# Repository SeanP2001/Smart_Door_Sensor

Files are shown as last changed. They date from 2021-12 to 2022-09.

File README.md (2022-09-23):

# Smart Door Sensor Project

## Table of Contents

* [Table of Contents](#table-of-contents)
* [Introduction](#introduction)
* [Brief](#brief)
* [Method of Operation](#method-of-operation)
  + [Setting up The Device](#setting-up-the-device)
  + [Using the Device](#using-the-device)
* [Circuitry](#circuitry)
  + [Full Schematic](#full-schematic)
  + [Veroboard Prototype](#veroboard-prototype)
  + [PCB](#pcb)
* [Further Work](#further-work)

## Introduction

This originally started as a university project, and I have continued to develop this idea in my spare time.

## Brief

This project is a smart door alarm for security in university accommodation and hotel rooms. When somebody enters the room, the buzzer will sound, or the device will email the user. This standalone device does not require a smart hub to operate.

## Method of Operation

<p align="center">
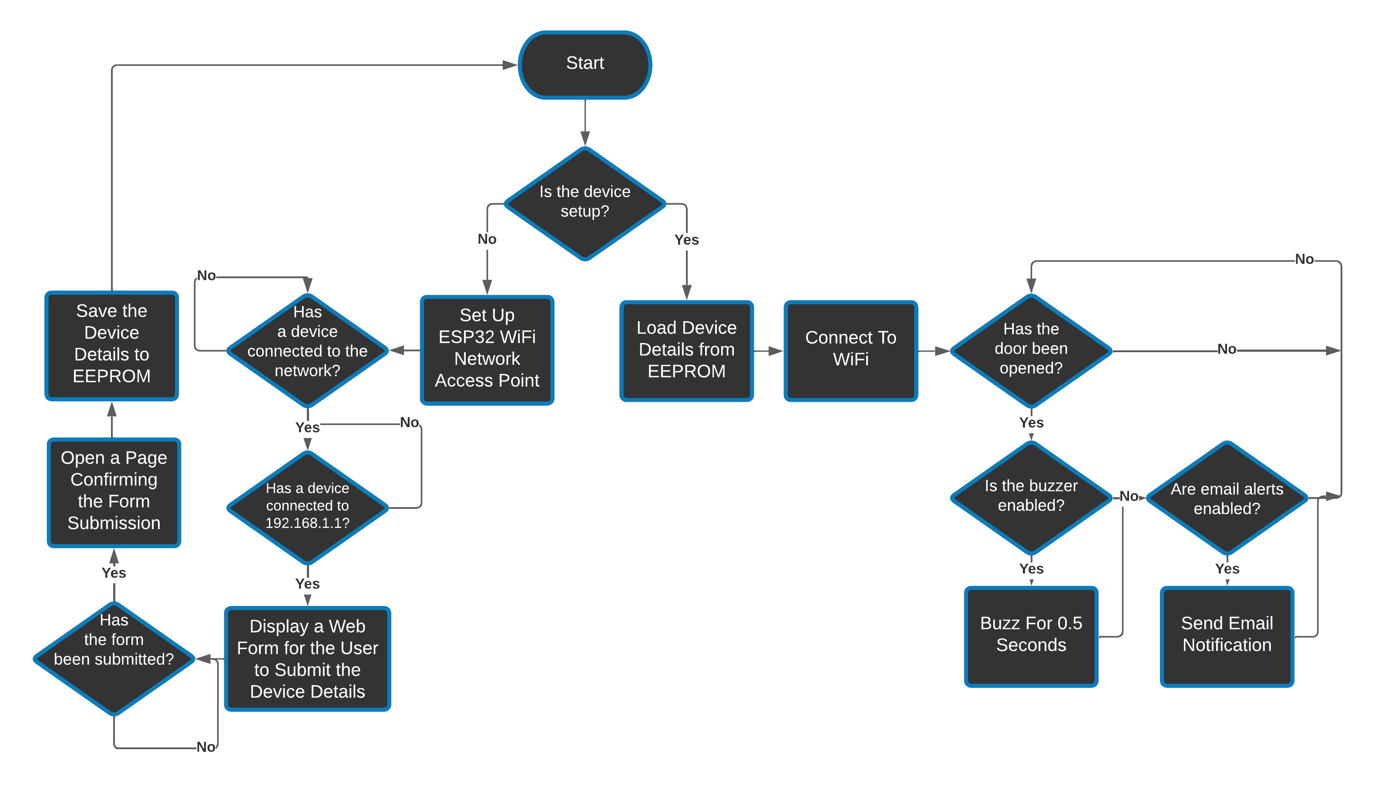
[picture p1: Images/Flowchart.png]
  
</p>

### Setting up The Device

1. Plug the device into a phone charger and switch the charger on.

2. Open the Wi-Fi settings on your smartphone and wait for the “S.P.U.D Smart
   System” network to appear. Once it appears, connect to it.

3. Turn off mobile data on your phone.

4. Open your phone’s web browser and enter “192.168.1.1” into the address bar.
   
   <p align="center">
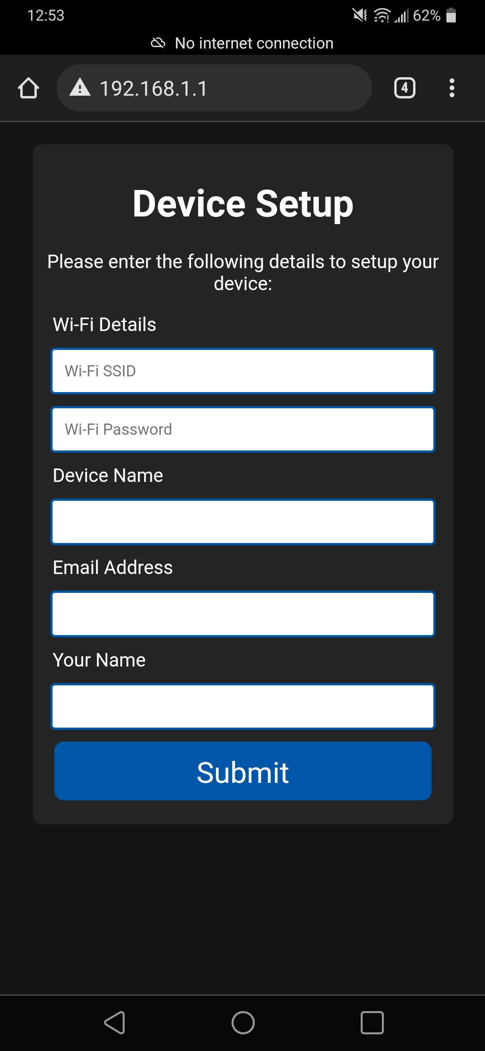
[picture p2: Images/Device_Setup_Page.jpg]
     
   </p>

5. When the page loads, input the following information:
   • Wi-Fi SSID - The name of your Wi-Fi network
   • Wi-Fi Password - Often found on the back of your Wi-Fi router
   • Device Name - The name which you want to give the device e.g., “Front Door”
   • Email Address - The email address to send notifications to
   • Your Name - The name which you want to appear on the email notifications

6. Press “Submit” and check that the credentials displayed on the next page are
   correct.

7. Wait for the LED on the device to flash green and then turn off the device and
   turn it back on again.

8. Now your device is setup.

9. Attach the sensor to the back of the door. Peel the sticky back off the main
   body and stick it to the edge of the door. Stick the magnetic contact to the
   door frame, as close to the sensor as possible. (Image showing device
   attached to door)

10. Open the door ensuring that the device does not catch on the door.

### Using the Device

<p align="center">
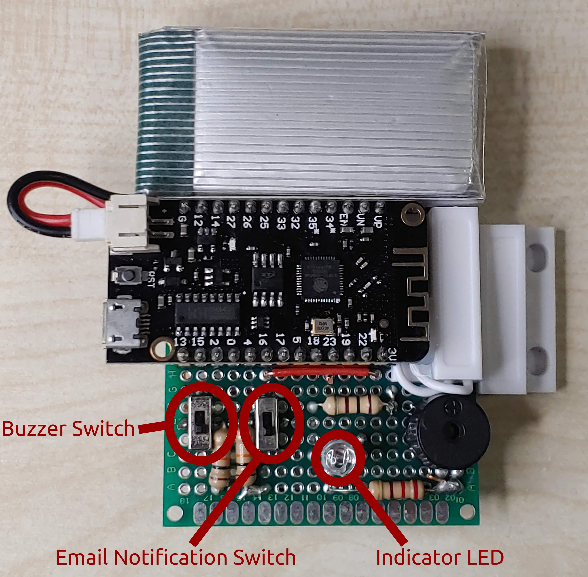
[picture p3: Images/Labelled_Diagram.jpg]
  
</p>

Switching either of the switches will alter the settings and cause the indicator LED to light (The colour of the LED shows which setting has changed).

| Indicator LED Colour | Meaning |
| --- | --- |
| Blue | Buzzer ON |
| Yellow | Buzzer OFF |
| Green | Email Notifications ON  |
| Red | Email Notifications OFF |

Depending on the settings, the sensor will either buzz or send an email notification when the door is opened.

## Circuitry

### Full Schematic

<p align="center">
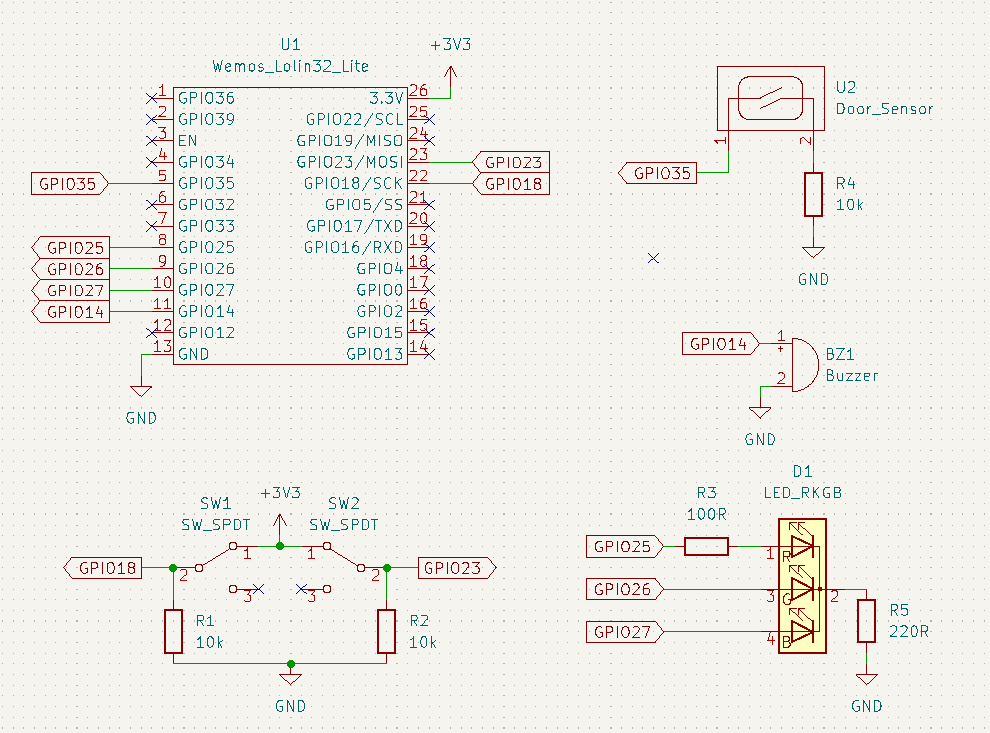
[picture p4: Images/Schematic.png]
  
</p>

### Veroboard Prototype

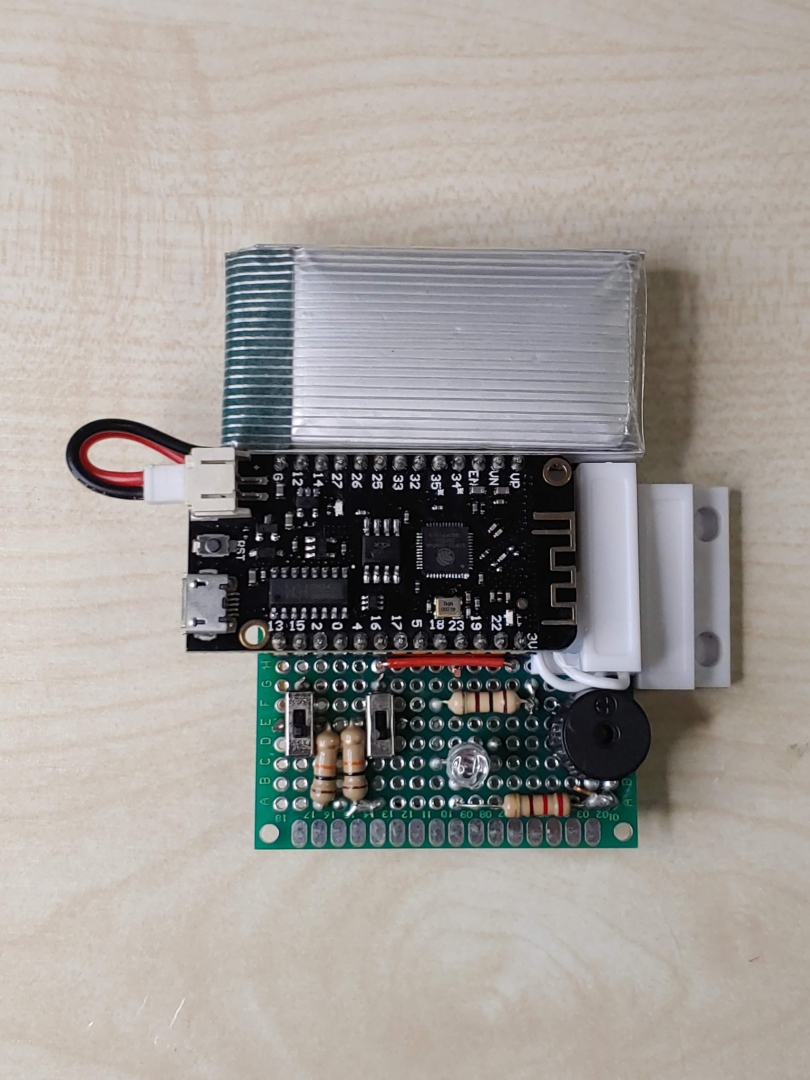
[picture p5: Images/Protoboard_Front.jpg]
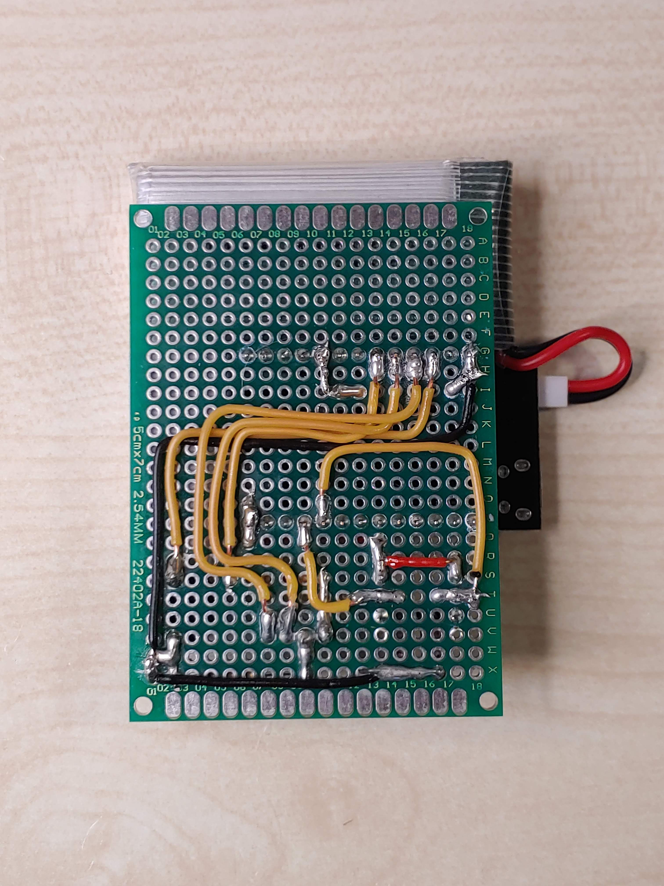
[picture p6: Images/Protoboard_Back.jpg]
|  |  |
| --- | --- |

### PCB

<p align="center">
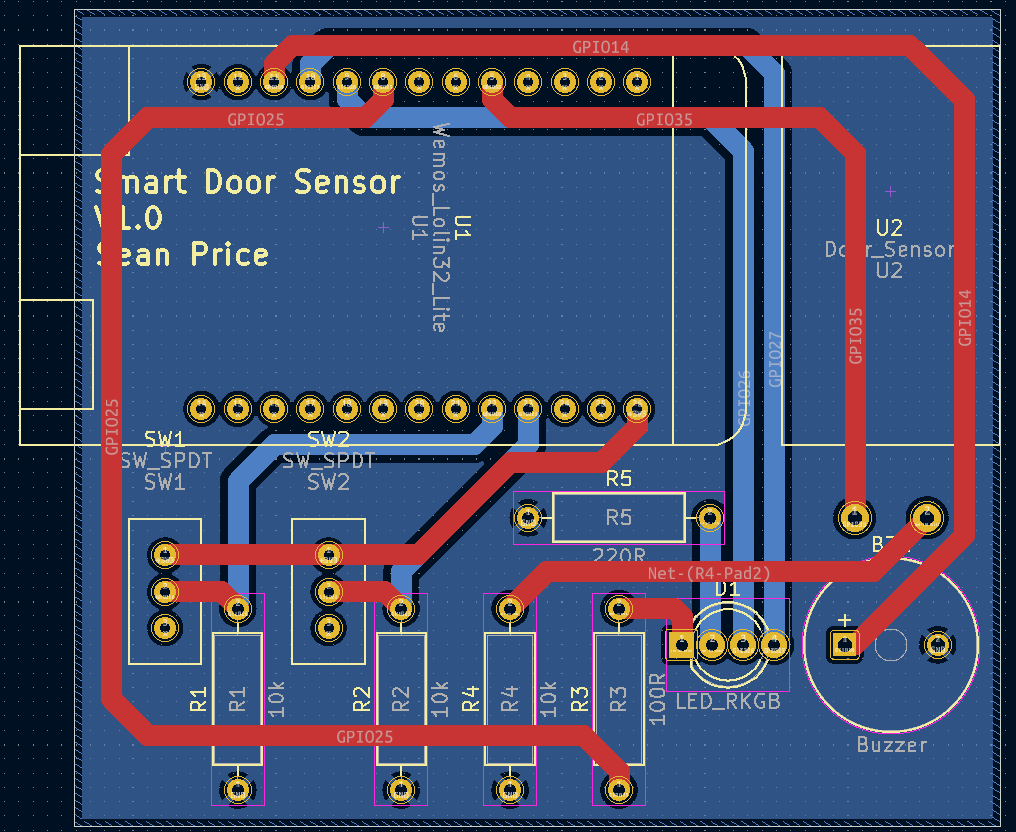
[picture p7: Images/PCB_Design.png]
  
</p>

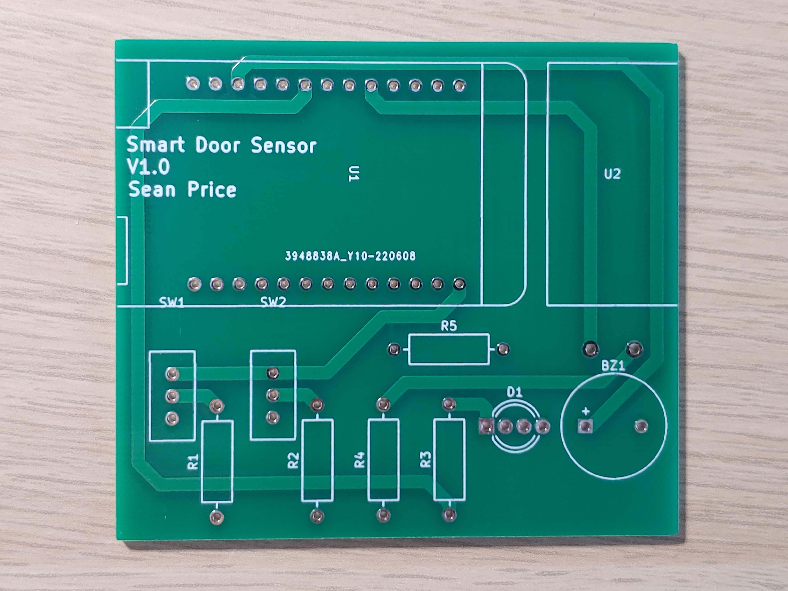
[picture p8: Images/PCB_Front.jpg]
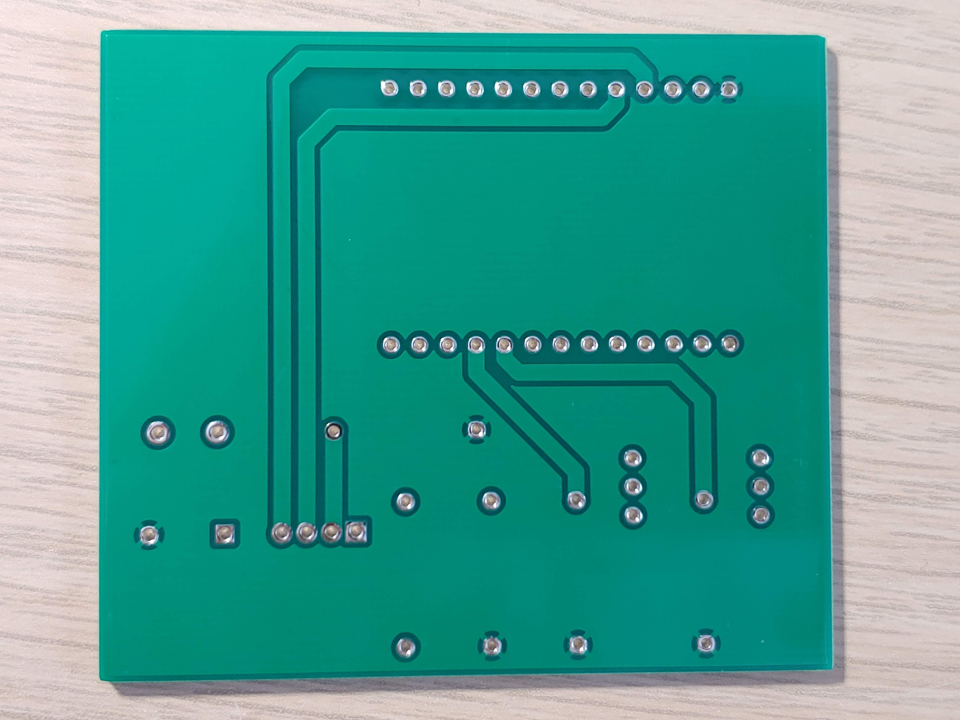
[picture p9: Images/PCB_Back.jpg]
|  |  |
| --- | --- |

## Further Work

I will be working to re-design the board for this project. I want to use a latch to power the microcontroller when the door is opened and power it off once it has sent the email. This will reduce power consumption.

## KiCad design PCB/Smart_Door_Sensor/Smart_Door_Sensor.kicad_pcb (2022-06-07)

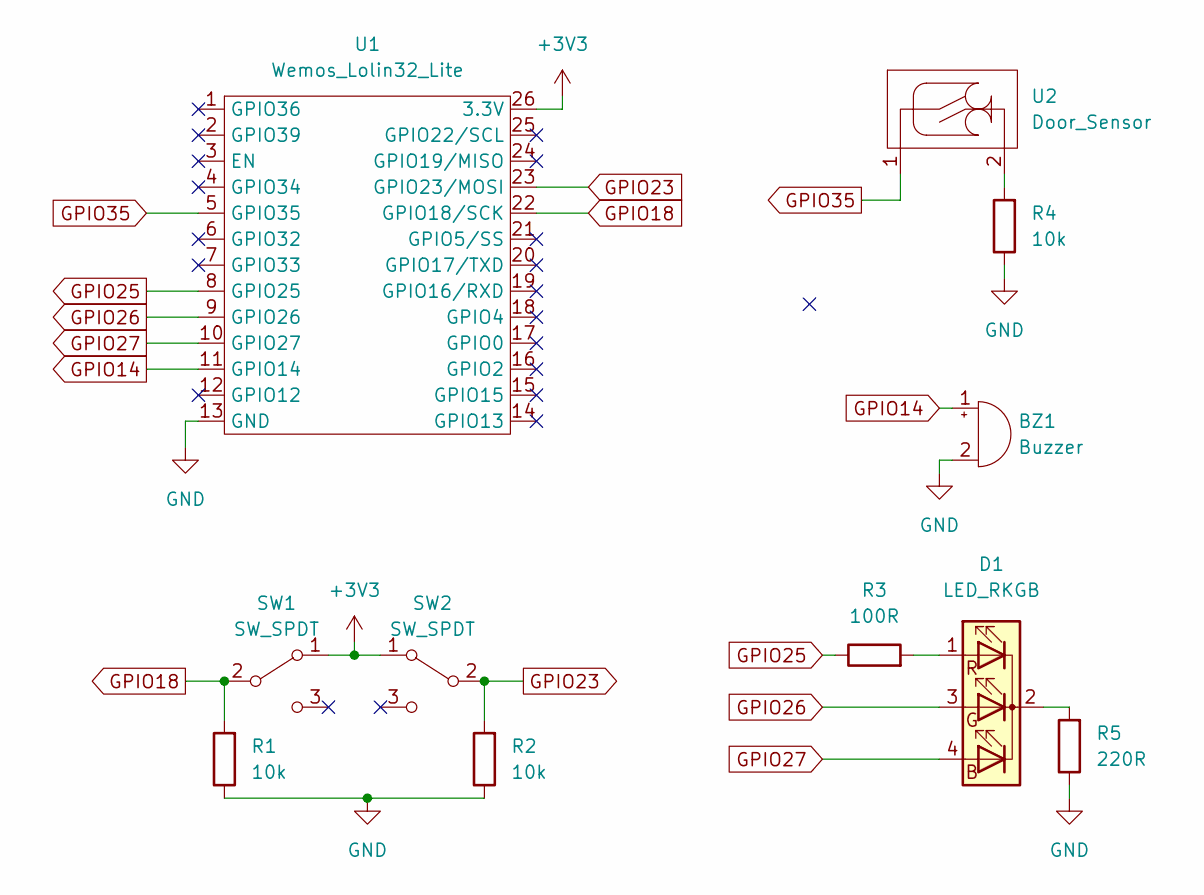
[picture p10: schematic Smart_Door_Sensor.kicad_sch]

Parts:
BZ1: Buzzer; MagneticBuzzer_ProSignal_ABT-410-RC
D1: LED_RKGB; LED_D5.0mm-4_RGB_Wide_Pins
R1, R2, R4: 10k; R_Axial_DIN0309_L9.0mm_D3.2mm_P12.70mm_Horizontal
R3: 100R; R_Axial_DIN0309_L9.0mm_D3.2mm_P12.70mm_Horizontal
R5: 220R; R_Axial_DIN0309_L9.0mm_D3.2mm_P12.70mm_Horizontal
SW1, SW2: SW_SPDT; SPDT_Slide_Switch
U1: Wemos_Lolin32_Lite
U2: Door_Sensor

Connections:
+3V3: SW1.1 (A), SW2.1 (A), U1.26 (3.3V)
GND: BZ1.2 (+), R1.1, R2.1, R4.1, R5.1, U1.13 (GND)
GPIO14: BZ1.1 (-), U1.11 (GPIO14)
GPIO18: R1.2, SW1.2 (B), U1.22 (GPIO18/SCK)
GPIO23: R2.2, SW2.2 (B), U1.23 (GPIO23/MOSI)
GPIO25: R3.1, U1.8 (GPIO25)
GPIO26: D1.3 (GA), U1.9 (GPIO26)
GPIO27: D1.4 (BA), U1.10 (GPIO27)
GPIO35: U1.5 (GPIO35), U2.1
unnamed: D1.1 (RA), R3.2
unnamed: D1.2 (K), R5.2
unnamed: R4.2, U2.2

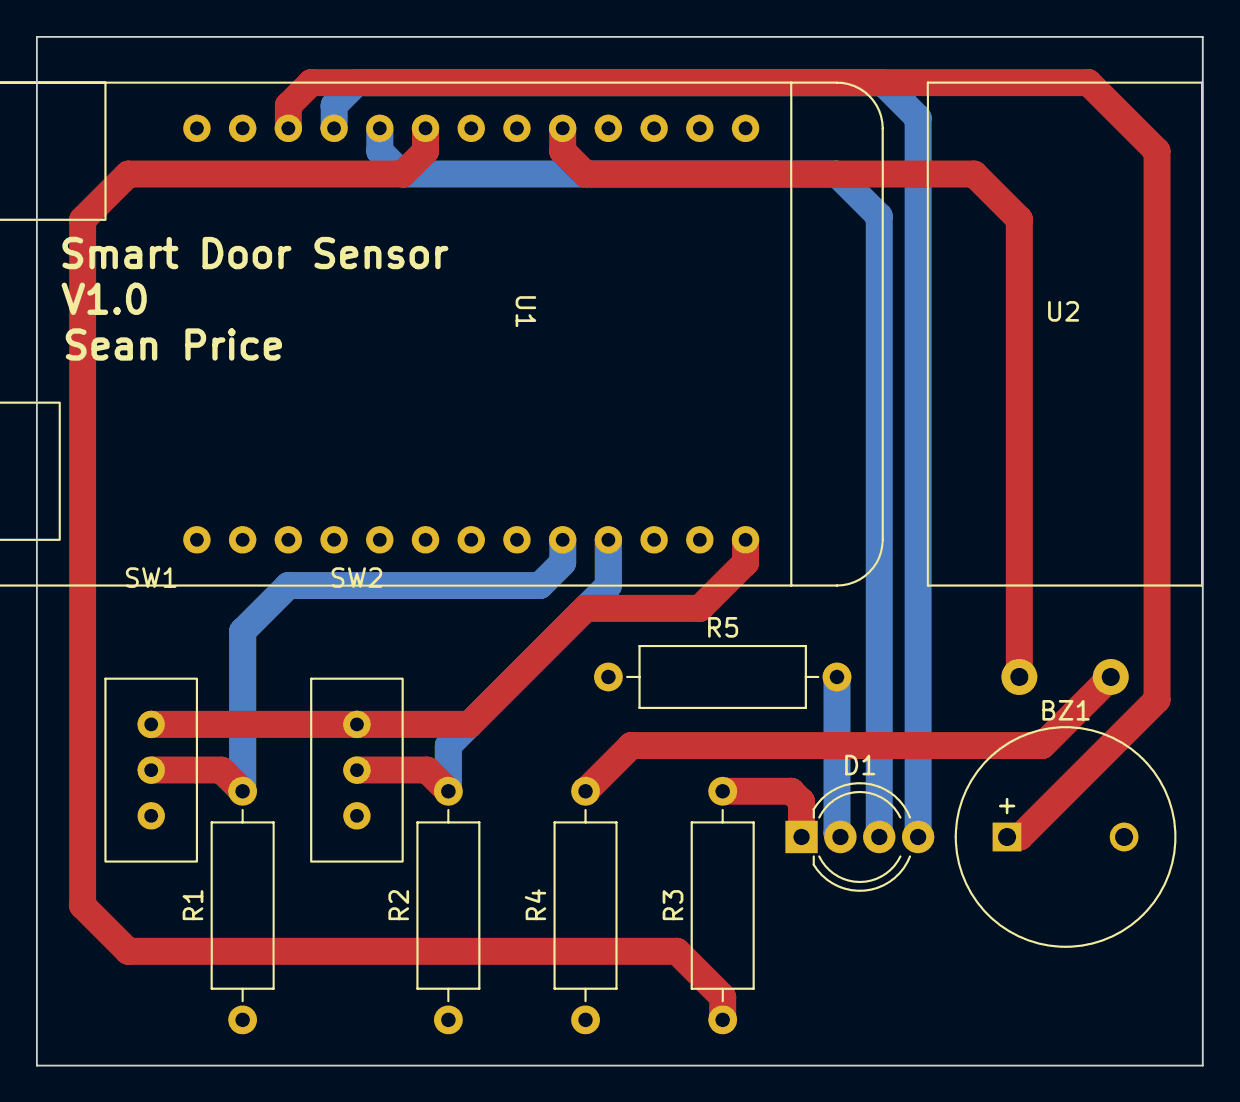
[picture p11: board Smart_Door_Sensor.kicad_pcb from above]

Board: 2 copper layers, 64.8 x 57.2 mm, 11 parts (0 on the bottom side), 12 nets.

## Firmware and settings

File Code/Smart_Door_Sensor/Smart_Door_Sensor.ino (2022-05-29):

/*
 * S.P.U.D Smart System - Door Sensor
 *
 * Works with LOLIN32 Lite, after installation of ESP32 Arduino Core:
 * In Arduino IDE set:
 * Set Board to "WEMOS LOLIN32"
 * Set Upload Speed 115200
 */

#include "ConnectWiFi.h"
#include "SendEmail.h"
#include "SaveAndLoadDetails.h"
#include "RGBLED.h"
#include "DeviceSetup.h"

#include <ESP32Servo.h>  // only needed for tone

// ----------------------------------------------------------------- D E V I C E   D E T A I L S   V A R I A B L E S -----------------------------------------------------------------
struct deviceDetails {
  char wifiSSID[30];
  char wifiPassword[30];
  char deviceName[30];
  char emailAdd[30];
  char userName[15];
  bool isSetup;
};

deviceDetails device{
  "",
  "",
  "",
  "",
  "",
  false
};

// ----------------------------------------------------------------- W I F I   A C C E S S   P O I N T   D E T A I L S -----------------------------------------------------------------
const char* wifiAPSSID = "S.P.U.D Smart System";
IPAddress local_ip(192,168,1,1);
IPAddress gateway(192,168,1,1);
IPAddress subnet(255,255,255,0);

// ------------------------------------------------------------------------------ E M A I L   A L E R T S ------------------------------------------------------------------------------
const char* emailSubject = "Door Open";
const char* messageText = "Your room door has been opened";

// ------------------------------------------------------------------------------ D E C L A R E   P I N S ------------------------------------------------------------------------------
int ledPin = 22;                                            // onboard led is on pin 22
int buzzerPin = 14;                                         // buzzer connected to pin 14

// ----------------------------------------------------------------------------- R G B   L E D   S E T U P -----------------------------------------------------------------------------
int redLEDPin = 25;                                         // RGB LED red leg on pin 25 
int greenLEDPin = 26;                                       // RGB LED green leg on pin 26
int blueLEDPin = 27;                                        // RGB LED blue leg on pin 27

RGBLED indicatorLED(redLEDPin, greenLEDPin, blueLEDPin);    // instantiate an RGB LED

// ---------------------------------------------------------------------------- S E T U P   S W I T C H E S ----------------------------------------------------------------------------
int emailSwitchPin = 23;                                    // switch to enable or disable email notifications on pin 23
int buzzerSwitchPin = 18;                                   // switch to enable or disable the buzzer on pin 23

bool emailAlert;                                            // a boolean variable to store whether email notifications are enabled or disabled
bool buzzerAlert;                                           // a boolean variable to store whether the buzzer is enabled or disabled

// ------------------------------------------------------------------------- D O O R   S E N S O R   S E T U P -------------------------------------------------------------------------
int doorSwitchPin = 35;                                     // door reed switch on pin 19

enum State {CLOSED, OPEN};                                  // the state of the door is either closed or open

bool currentState = CLOSED;                                 // variable storing the current state of the door
bool previousState = CLOSED;                                // variable storing the previous state of the door

int switchTime = 0;                                         // varaible storing the last time that the state changed
int debounceDelay = 200;                                    // how long to wait to cancel out switch bounce (false inputs)



// ------------------------------------------------------------------------------------- S E T U P -------------------------------------------------------------------------------------
void setup()
{
  pinMode(ledPin, OUTPUT);                                    // set the LED pin as an output
  pinMode(doorSwitchPin, INPUT);                              // set the reed switch as an input
  pinMode(emailSwitchPin, INPUT);                             // set the email notification switch as an input
  pinMode(buzzerSwitchPin, INPUT);                            // set the buzzer switch as an input
  pinMode(buzzerPin, OUTPUT);                                 // set the buzzer as an output 
  
  Serial.begin(115200);                                       // start serial communication

  device = loadDetails();                                     // load the device details 

  printDetails(device);                                       // print the details which have been loaded

  if (device.isSetup){                                        // if the device has been setup
    setupWiFi(device.wifiSSID, device.wifiPassword);          // Connect to the WiFi
  }

  emailAlert = digitalRead(emailSwitchPin);                   // set the email alerts to be enabled or disable based on the current position of the email switch
  buzzerAlert = digitalRead(buzzerSwitchPin);                 // set the buzzer to be enabled or disabled based on the current position of the buzzer switch
  
  digitalWrite(ledPin, HIGH);                                 // turn the LED off (ACTIVE LOW) 
}


// -------------------------------------------------------------------------------------- M A I N --------------------------------------------------------------------------------------
void loop()
{
// ------------------------------------------------------------------------------ I F   N O T   S E T U P ------------------------------------------------------------------------------
  if (!device.isSetup)                                                                    // If the device has not been setup
  {
    setupWiFiAP(wifiAPSSID, local_ip, gateway, subnet);                                   // setup wifi access point

    Serial.print("\nWaiting");
     
    while(!isClientConnected()){                                                          // Wait for a connection
      Serial.print(".");
      delay(200);
    }
    
    device = getCredsViaWebAP();                                                          // once a device has connected, send the credentials web form and get the submission                                                     
    saveDetails(device);                                                                  // Save the device details  
    indicatorLED.flashLED(RGBLED::GREEN, 1000);                                           // flash green
  }

// ---------------------------------------------------------------------------------- I F   S E T U P ----------------------------------------------------------------------------------
  else                                                                                    // If the device has been setup
  {  
    currentState = digitalRead(doorSwitchPin);                                            // Set the current state of the door based on the reading from the reed switch
  
    if ((currentState != previousState) && ((millis() - switchTime) >= debounceDelay))    // if the door has changed state and the debounce delay time has passed
    {
      switchTime = millis();                                                              // log the time when the door state changed
      
      if (currentState == OPEN)                                                           // if the door is open
      {
        digitalWrite(ledPin, LOW);                                                        // turn the LED on (ACTIVE LOW)
        Serial.println("Door Open");                                                      // print "Door Open" to the serial monitor
        

        if(buzzerAlert)                                                                   // If the buzzer is enabled
        {
            tone(buzzerPin, 2000);                                                        // sound the buzzer
            delay(500);
            noTone(buzzerPin);
        }
        if(emailAlert)                                                                    // If email alerts are enabled
        {
          sendEmail(device.emailAdd, device.userName, emailSubject, messageText);         // send the user an email
        }
        previousState = OPEN;                                                             // set the previous state to OPEN ready for the next loop
      }
      
      if (currentState == CLOSED)                                                         // if the door is closed
      {
        digitalWrite(ledPin, HIGH);                                                       // turn the LED off (ACTIVE LOW)           
        Serial.println("Door Closed");                                                    // print "Door Open" to the serial monitor
        previousState = CLOSED;                                                           // set the previous state to CLOSED ready for the next loop
      }
    }
    
    if(digitalRead(emailSwitchPin) != emailAlert)                                         // if the email alerts switch has changed states
    {
      if(digitalRead(emailSwitchPin) == HIGH)                                             // and emails have been enabled
      {
        indicatorLED.flashLED(RGBLED::GREEN, 500);                                        // flash green
        emailAlert = true;                                                                // and set the email alerts to enabled
      }
      if(digitalRead(emailSwitchPin) == LOW)                                              // if the email alerts have been disabled
      {
        indicatorLED.flashLED(RGBLED::RED, 500);                                          // flash red
        emailAlert = false;                                                               // and set the email alerts to disabled
      } 
    }
    
    if(digitalRead(buzzerSwitchPin) != buzzerAlert)                                       // if the buzzer switch has changed states           
    {
      if(digitalRead(buzzerSwitchPin) == HIGH)                                            // and it has been enabled
      {
        indicatorLED.flashLED(RGBLED::BLUE, 500);                                         // flash blue
        buzzerAlert = true;                                                               // and set the buzzer to enabled
      }
      if(digitalRead(buzzerSwitchPin) == LOW)                                             // if the buzzer has been disabled
      {
        indicatorLED.flashLED(RGBLED::YELLOW, 500);                                       // flash yellow
        buzzerAlert = false;                                                              // and set the buzzer alerts to disabled
      } 
    }
  }   
}

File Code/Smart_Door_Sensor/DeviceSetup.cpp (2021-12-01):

#include "DeviceSetup.h"

AsyncWebServer server(80);                       // instantiate the webserver

struct deviceDetails {                           
  char wifiSSID[30];
  char wifiPassword[30];
  char deviceName[30];
  char emailAdd[30];
  char userName[15];
  bool isSetup;
};

// ----------------------------------------------------------------- H T M L   F I E L D   N A M E S -----------------------------------------------------------------
const char* WIFI_SSID_FIELD = "wifissid";        
const char* WIFI_PASS_FIELD = "wifipass";
const char* DEVICE_NAME_FIELD = "devname";
const char* EMAIL_ADD_FIELD = "emailadd";
const char* USER_NAME_FIELD = "username";

// ------------------------------------------------- S T R I N G S   T O   S T O R E    F I E L D    C O N T E N T S -------------------------------------------------
String wifiSSID;
String wifiPassword;
String deviceName;
String emailAdd;
String userName;

// -------------------------------------------------------------------- H T M L   W E B   F O R M --------------------------------------------------------------------
const char index_html[] PROGMEM = R"rawliteral(
<!DOCTYPE HTML><html><head>
  <title>Device Setup</title>
  <meta name="viewport" content="width=device-width, initial-scale=1">
  <style>
  body{color:white; background-color:#141414; font-family: Helvetica, Verdana, Arial, sans-serif}
  h1{text-align:center;}
  p{text-align:center;}
  div{margin: 5%; background-color:#242424; padding:10px; border-radius:8px;}
  br{display: block; margin: 10px 0; line-height:22px; content: " ";}
  label{text-align:left; padding:2%;}
  input{border-radius: 4px; border: 2px solid #0056a8; width:90%; padding:10px; display:block; margin-right:auto; margin-left:auto;}
  input[type="submit"]{font-size: 25px; background-color:#0056a8; color:white; border-radius:8px; height:50px; width:95%;}
  </style>
  </head><body>
  <div>
    <h1>Device Setup</h1>
    <p>Please enter the following details to setup your device:</p>
    <form action="/get">
      <label>Wi-Fi Details</label>
      <br>
      <input type="text" name="wifissid" id="wifissid" placeholder="Wi-Fi SSID">
      <br>
      <input type="password" name="wifipass" id="wifipass" placeholder="Wi-Fi Password">
      <br>
      <label for="devname">Device Name</label>
      <br>
      <input type="text" name="devname" id="devname">
      <br>
      <label for="emailadd">Email Address</label>
      <br>
      <input type="email" name="emailadd" id="emailadd">
      <br>
      <label for="username">Your Name</label>
      <br>
      <input type="text" name="username" id="username">
      <br>
      <input type="submit" value="Submit">
    </form><br>
  </div>
</body></html>)rawliteral";

// ----------------------------------------------------------------- W E B P A G E   N O T   F O U N D -----------------------------------------------------------------
void notFound(AsyncWebServerRequest *request) {
  request->send(404, "text/plain", "Not found");
}

// ---------------------------------------------- G E T   C R E D E N T I A L S   V I A   W E B   A C C E S S   P O I N T ----------------------------------------------
struct deviceDetails getCredsViaWebAP()
{
  deviceDetails formSubmission{                                             // struct to store credentials
    "",
    "",
    "",
    "",
    "",
    false
  };

  server.on("/", HTTP_GET, [](AsyncWebServerRequest *request){              // when the user goes to the server IP 
    request->send_P(200, "text/html", index_html);                          // send the contents of index_html (the web form)
  });

  server.on("/get", HTTP_GET, [] (AsyncWebServerRequest *request) {         // when the user goes to the form submitted page
    
    if (request->hasParam(WIFI_SSID_FIELD)) {                               // if the wifi field has been filled out get the contents from each field and store in a string
      wifiSSID = request->getParam(WIFI_SSID_FIELD)->value();
      wifiPassword = request->getParam(WIFI_PASS_FIELD)->value();
      deviceName = request->getParam(DEVICE_NAME_FIELD)->value();
      emailAdd = request->getParam(EMAIL_ADD_FIELD)->value();
      userName = request->getParam(USER_NAME_FIELD)->value();
    }
    else {                                                                  // if the SSID field has no contents, then all fields have no contents
      wifiSSID = "";
      wifiPassword = "";
      deviceName = "";
      emailAdd = "";
      userName = "";
    }
    
    Serial.println(wifiSSID);                                               // print out the contents of all fields
    Serial.println(wifiPassword);
    Serial.println(deviceName);
    Serial.println(emailAdd);
    Serial.println(userName);

    // \/ send the form submission page \/
    request->send(200, "text/html", "<meta name=viewport content=width=device-width, initial-scale=1><style>body{color:white; text-align:center; background-color:#141414; font-family: Helvetica, Verdana, Arial, sans-serif}div{margin: 5%; background-color:#242424; padding:10px; border-radius:8px;}br{display: block; margin: 10px 0; line-height:22px; content: " ";}table{margin-left: auto; margin-right: auto;}</style>"
                                    "<body><div><h1>Device Settings</h1>"
                                    "<table><tr><td><b>Wi-Fi SSID: </b></td><td>" + wifiSSID
                                  + "</td></tr><tr><td><b>Wi-Fi Password: </b></td><td>" + wifiPassword
                                  + "</td></tr><tr><td><b>Device Name: </b></td><td>" + deviceName 
                                  + "</td></tr><tr><td><b>Email Address: </b></td><td>" + emailAdd 
                                  + "</td></tr><tr><td><b>Your Name: </b></td><td>" + userName + "</td></tr></table>");
  });
  server.onNotFound(notFound);   // if the webpage can't be found, send a 404
  server.begin();


  
  while(1)                                                         // loop forever (wait)     
  {
    if (wifiSSID != "")                                            // if the wifi ssid is not empty
    { 
      Serial.println("Form Submitted");                            // print to the console that the form has been submitted

      wifiSSID.toCharArray(formSubmission.wifiSSID, 30);           // convert all of the strings to char arrays and populate the formSubmission struct
      wifiPassword.toCharArray(formSubmission.wifiPassword, 30);
      deviceName.toCharArray(formSubmission.deviceName, 30);
      emailAdd.toCharArray(formSubmission.emailAdd, 30);
      userName.toCharArray(formSubmission.userName, 15);

      formSubmission.isSetup = true;                               // mark the setup as complete
    
      return formSubmission;                                       // return the contents of the formSubmission struct
    }   
  }
}

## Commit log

2021-11-22 V0.1 LED switches on and off in response to a reed switch
2021-11-22 V0.2 The device sends an email whenever the door is opened
2021-11-29 V0.4 Added buzzer, buzzer switch, email switch and RGB indicator LED
    [RGBLED.cpp, Smart_Door_Sensor.ino]
2021-12-01 V0.5 Added device setup via ESP32 access point
2022-05-29 V0.6 Designed PCB
    [Smart_Door_Sensor.kicad_pcb, Smart_Door_Sensor.kicad_sch]
2022-06-02 V0.6.1 Exported gerber files
2022-06-07 V0.6.2 Finalised PCB V1.0
    [Smart_Door_Sensor-B_Cu.gbl, Smart_Door_Sensor-B_Mask.gbs, Smart_Door_Sensor-B_Paste.gbp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]
